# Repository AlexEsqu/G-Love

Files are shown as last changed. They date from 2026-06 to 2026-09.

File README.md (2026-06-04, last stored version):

https://app.notion.com/p/G-Love-Module-Electronique-06-26-42-Chips-371a25cc104180e3b6d8d438b70a2ca8

# Presentation

[G-Love] est un projet de conception d’un système de vêtement électronique (wearable) porté sur les bras., intégrant des bandes LEDSs RGB réactives à l’environnement et aux mouvements du porteur. (acceleration, flexion, pression)

Le système se présente sous forme de gant relié à une manchette d’avant-bras parcourus de capteurs et de LEDs. Un capteur sur le poignet permet de naviguer entre les modes.

---

# Table des matieres

---

# 1.Manuel d’utilisation

## Interactions

- Sur flexion / pression d’un doigt : animation localisée sur le segment correspondant
- Mouvement brusque du bras : traînée lumineuse, onde ?
- Orientation du bras : dégradé de couleur selon l’axe
- Bonus DMX : LEDs pilotees par reception DMX / Gestion d’une scene en transmission DMX

## Parametrage

- Pression bracelet : changement de mode pour passer d’un preset a l’autre
- Switch : pour demarrer avec ou sans feature LEDs
- Calibrage : via proximite aimant ou combinaison mouvement ?
- Bonus Touchscreen : Changer de mode / couleur

## Demarrage

Un utilisateur devra passer par une étape de calibration pour sa première utilisation du gant (longueur du bras et des doigts, amplitude de mouvement, calibration des senseurs…).
Mais les utilisations suivantes ne devraient pas nécessiter de vraie calibration, placer une nouvelle position d’origine au plus.

## Résumé

Les senseurs du gant devraient permettre de mesurer en temps réel la position de la main dans l’espace, la flexion des doigts, et les contacts avec le bout des doigts.

Les differents capteurs utilisés simultanément devraient permettre a l’utilisateur de déclencher plusieurs effets lumineux sur le display led, avec des combinaisons additives d’effets (mouvement + position des doigts X != mouvement + position Y != mouvement seul)

Ces mesures peuvent aussi être transmises en temps réel à une autre machine (à définir) pour lier ces mesures d’inputs à d’autres effets.

# 2.Features

---

## Mandatory

- 5 Ruban LED adressable sur les doigts, réagissant individuellement
- Interaction sur flexion d’un doigt (capteur flex a chaque doigt)
- Interaction sur pression du bout d’un doigt (capteur pression au bout de chaque doigt)
- Interaction sur :
    - mouvement de la main
    - l’orientation de la main
- Transmission coordonnée dans l’espace en temps réel par UART (précision dans la limite du matériel accessible avec le budget : plusieurs IMU, ou IMU plus précis, balise et triangulation…)
- Surface avant-bras LED adressable 16x16 / 16x64 (dans limite budget)
- Interaction sur l’avant bras (capteur pression)
- Envoi des donnees en USB via bridge USB to UART
- Système de reset des positions/mouvements (simple bouton ou combinaison d’input). Peut être nécessaire suivant le fonctionnement du capteur et la longueur d’utilisation.
- Système de calibration capable définir nouvelle origine (point 0,0,0) , sans reset tout le système. (si la calibration a été faite, un reset complet de la machine peut etre rattrappe en 2secondes si l’utilisateur garde une position de repos)

    Définir amplitude max du bras (bras tendu, leve, a plat sur les cuisses)

- Gestion embarquée de la chaleur des LEDs par capteur température et optimisation software ; utiliser des techno type textile conducteur, ??? pour permettre PLUS DE LED

## Bonus

#### Communication

- Interaction entre 2 gants dans le meme espace via coordonnees transmises en USB

#### TouchScreen

- Bonus: Touchscreen ou autre système d’input pour changer de mode/paramètres.

    Peut etre utile pour changer plus facilement les options pendant l‘utilisation de l’objet. Et pour visualiser les paramètres actuels sans trop perturber le display principal de l’objet.

#### DMX

- Bonus: Transmission DMX via driver RS-485 (MAX485 + XLR DMX)

    +Note: émission de format DMX probablement ingérable, réception semble plus réaliste.

#### FingerTip

- Bonus: Module Plug and Play HEARTBEAT capteur de pouls
- Bonus: Module Plug and play PISTODOIGT en infrarouge pour jouer au laser tag avec un doigt canon et le flex d’un autre doigt pour la gâchette  🔫
- Super Bonus : Module Plug and Play CURSOR permettant de dessiner en 3D ; Captation suffisamment précise pour dessiner un 42 lisible dans l’espace d’un 1m3

---

# 3. Schema fonctionnel

!Schema Fonctionnel.png

TO DO:
- formes logique
- légende
- ajouter ref compo

---

# 4. Matériel et protocoles

- **Microcontrôleurs relies UART** :
    - ATmega328P
    - ATmega32U4 (1 controleur principal pour les gouverner tous)
- **Bandes LEDs RGB** : WS2812B ou APA102 le long des doigts et panneau LEDs sur l’avant-bras
- **Capteurs** :

    **ADC** protocole **: Flex sensors** pour la flexion (duh), **FSR** (force-sensing resistor) pour la pression des doigts via multiplexeur CD4067

    **SPI / I2c** protocole **: IMU** (inertial measurement unit) pour accéléromètre + gyroscope,

    **Proximité** : Capteur Hall digital A3144

- **Support** : PCB Flex et PCB rigides avec segments flexibles entre chaque
- **Microcontrôleurs relies en UART** :
    - **ATmega328P (**main**)**
    - **ATmega2561** (avant-bras)
- **Capteurs** :

    **ADC** via multiplexer CD4067 **:**

    - **Flex sensors** pour la flexion des doigts
    - **FSR** (force-sensing resistor) pour la pression des doigts

    **I2C : IMU** (inertial measurement unit) pour accéléromètre + gyroscope

    **Digital I/O** :

    - **Capteur** Hall digital A3144
    - **bandes LEDs RGB** APA102 le long des doigts et panneau LEDs sur l’avant-bras
- **HeatSensor :** Utilisation de Thermistance NTC (negative temperature coefficient = la résistance diminue lorsque la température augmente), placé là où il y a le plus de variation de chaleur possible (rubans LED) avec de la colle thermique pour mieux capté la chaleur et recouvert d’un ruban Kapton pour isolé de l’air ambiant

- **Bonus SPI/I2C** : touchscreen, **GC9A01** est la puce qui contrôle l'affichage de l'écran et communique en SPI et **CST816D** est la puce qui contrôle la détection du tactile, communique en I2C
    - En sortie (Affichage - GC9A01) :
        - Afficher le mode d'interaction actuel (ex: "Mode DMX", "Mode Laser Tag")
        - Afficher des retours visuels lors de l'étape de calibration
    - En entrée (Saisie tactile - CST816D) :
        - Changement de mode: changement de mode pour différent interaction prédefini
        - Parametrage de couleurs: afficher une roue chromatique sur l'écran, permettant à l'utilisateur de sélectionner directement au doigt la couleur de base de ses bandes LED.
        - Bouton de secours / de reset: permet de déclencher manuellement un recalibration ou un “reset” en appuyant sur un bouton
- **Bonus UART** : USB
- **Bonus UART** : DMX
- **Support** : PCB Flex et PCB rigides avec segments flexibles entre chaque

## SPI (**Serial Peripheral Interface**)

SPI est un protocole ultra-rapide avec 4 fils : MOSI, MISO, SCK, CS. Fonctionnant sur une architecture de type master/slave, il permet des transferts de données bidirectionnels simultanenent  sans ralentir le microcontrôleur principal.

La synchronisation des échanges est assuré par un signal d’horloge généré exclusivement par le microcontroleur configuré en maitre

Le bus SPI repose sur l’utilisation de quatre lignes de signaux:

- SCK(Serial Clock) : Signal d’horloge generé par le maitre, il cadence le rythme de transmission des bits de données
- MOSI(Master Out Slave In) : Ligne de données unidirectionelle transportant les informations du maitre vers le slave
- MISO(Master In Slave Out) : ligne de données unidirectionelle transportant les informations du slave vers le maitre
- CS / SS (Chip Select / Slave Select) : Ligne d’activation dédié a chaque composant esclave, ce signal est actif a l’etat bas (0V), tant que le signal d’un esclave est haut, celui ci ignore le bus SPI et libere la ligne MISO
- Composant : Ruban LED APA102 (avant-bras).
    - **Le Maître :** L'ATmega328P est le maître du bus SPI
    - **Esclave :** Bandes LEDs APA102
    - **L'Usage :** Mise à jour à très haute fréquence de la matrice visuelle de l'avant-bras
    - **Câblage** : Utilise le D11(MOSI - Données) et D13 (SCK - Horloge)
- Composant : Ecran GC9A01
    - **Le Maitre** : L’ATMega2561 est le maitre du bus SPI
    - **Esclave :** L’écran GC9A01,
    - **L'Usage :** Le protocole SPI est un protocole assez rapide pour travailler et rafraichir un écran de 240x240pixels
    - **Cablage** : PB1(SCK - Horloge), PB2 (MOSI - Données), PB0 (SS/CS - Selection de l’ecran)

Les LED WS2812B utilise un protocole propriétaire de communication monofil, l’envoi des données à ces LED peut bloquer l’execution du programme et desactive les interruption du microcontrolleur

En choisissant les LED APA102 fonctionnant en SPI, la transmission de données est cadencée par la ligne d’horloge matérielle (SCK).  L’ATMega328P peut rafraichir l’affichage des LED sans aucune contrainte de temps grace au protocole SPI, lui permettant de simultanément et sans latences les capteurs

L’utilisation du protocole SPI pour l’affichage de l’ecran du TouchScreen permet aussi d’atteindre un taux de rafaichissement d’écran plus élevé et fluide avec 8MHz avec l’atm2561 contre 400kHz en I2C

## I2C **(Inter-Integrated Circuit)**

Le protocole I2C est un standard de communication bidirectionnel, il repose sur un principe d’adressage logiciel et permet de facilement reliée un microcontrolleur et différents circuits.

Contrairement au SPI qui necessite une ligne individuelle (Chip Select) par peripherique, le protocole I2C permet de connecter plusieurs dizaines de composants en parallele sur seulement deux lignes de communication:

- SCL (Serial Clock) : Signal d’horloge generé par le maitre pour cadencer la transmission des bits
- SDA (Serial Data) : Ligne de données bidirectionnelle transportant alternativement les informations du maitre vers le slave, et du slave vers le maitre

Adressage Unique: Chaque esclave I2C possède une adresse codée en binaire définie en usine ou par configuration matérielle. Le maitre commence chaque interaction en envoyant l’adresse du composant visé sur le fil SDA. Seul le composant possédant cette adresse répond, les autres ignorant la suite des paquets.

- Composant : ICM-42699-P
    - **Le Maitre** : L’ATMega328P est le maitre du bus I2C
    - **Esclave :**  ICM-42699-P
    - **L'Usage :** Le protocole I2C est
    - **Cablage** : SDA et SDL
- Composant : ecran tactile CST816D
    - **Le Maitre** : L’ATMega2561 est le maitre du bus I2C
    - **Esclave :**  CST816D
    - **L'Usage :** Le protocole I2C est
    - **Cablage** : SDA et SDL

L’adoption de l’I2C pour la gestion des capteurs de position et l’interaction tactile du TouchScreen:

- Minimisation de l’encombrement du cablage
    - L’I2C permet de connecter l’IMU et l’ecran tactile en n’utilsaint que 2 lignes de données, evitant de saturer les pins des micronctrolleur et d’alourdir le cablage flexible du bras
- Echange de données plus lent
    - Contraireemnt à l’écran LCD, le tactile et l’IMU ne transmettenet que de petit paquets de données, la vitesse de l’I2C est suffisante pour l’echange de donnée

## UART (Universal Asynchronous Receiver-Transmitter)

## ADC

## DIGITAL I/O

---

# 5. Pinout

## ATmega328p — Concentrateur capteurs + APA102

### MANDATORY

#### ALIMENTATION & PROGRAMMATION

| Pin | Composant | Signal / rôle | Protocole |
| --- | --- | --- | --- |
| **VCC / GND** | Alim | 5V — 100nF par paire VCC/GND | PWR |
| **RESET** | Reset | Pull-up 10kΩ vers VCC | Reset |

---

#### CRYSTAL OSCILLATOR

| Pin | Composant | Signal / rôle | Protocole |
| --- | --- | --- | --- |
| **B6 / XTAL1** | Crystal / Oscillator | External Clock |  |
| **B7 / XTAL2** | Crystal / Oscillator | External Clock |  |

---

#### ADC + MULTIPLEXER

| Pin | Composant | Signal / rôle | Protocole |
| --- | --- | --- | --- |
| **C0** | CD4067 S0 | Sélection canal multiplexeur | Digital |
| **C1** | CD4067 S1 | Sélection canal multiplexeur | Digital |
| **C2** | CD4067 S2 | Sélection canal multiplexeur | Digital |
| **C3** | CD4067 S3 | Sélection canal multiplexeur | Digital |
| **ADC7** | CD4067 output | Multiplex FSR doigts + Flex | ADC |
| **ADC6** | FSR 402 poignet | Capteur de force | ADC |

---

#### I2C IMU

| Pin | Composant | Signal / rôle | Protocole |
| --- | --- | --- | --- |
| **C4 / SDA** | ICM-42688 | IMU SDA | I2C |
| **C5 / SCL** | ICM-42688 | IMU SCL | I2C |

---

#### GPIO Hall

| Pin | Composant | Signal / rôle | Protocole |
| --- | --- | --- | --- |
| **D6** | A3144 Hall | Capteur magnétique | GPIO |

---

#### SPI LEDs

| Pin | Composant | Signal / rôle | Protocole |
| --- | --- | --- | --- |
| **B4** | APA102 ruban #1 | CS ruban 1 | GPIO CS |
| **B3 / MOSI** | APA102 DI (tous) | Data SPI — bus commun | SPI HW |
| **B5 / SCK** | APA102 CI (tous) | Clock SPI — bus commun | SPI HW |

---

#### BONUS UART

| Pin | Composant | Signal / rôle | Protocole |
| --- | --- | --- | --- |
| **D0 / RX** | ATmega2561 | RX ← TX du 2561 | UART |
| **D1 / TX** | ATmega2561 | TX → RX du 2561 | UART |

---

#### RECAP

| Pin | Composant | Signal / rôle | Protocole |
| --- | --- | --- | --- |
| **C0** | CD4067 S0 | Sélection canal multiplexeur | Digital |
| **C1** | CD4067 S1 | Sélection canal multiplexeur | Digital |
| **C2** | CD4067 S2 | Sélection canal multiplexeur | Digital |
| **C3** | CD4067 S3 | Sélection canal multiplexeur | Digital |
| **ADC7** | CD4067 output | Multiplex FSR doigts + Flex | ADC |
| **D6** | A3144 Hall | Capteur magnétique | Digital IN |
| **B4** | APA102 ruban #1 | CS ruban 1 | GPIO CS |
| **B3 / MOSI** | APA102 DI (tous) | Data SPI — bus commun | SPI HW |
| **B5 / SCK** | APA102 CI (tous) | Clock SPI — bus commun | SPI HW |
| **ADC6** | FSR 402 poignet | Capteur de force | ADC |
| **C4 / SDA** | ICM-42688 | IMU SDA | I2C |
| **C5 / SCL** | ICM-42688 | IMU SCL | I2C |
| **B6 / XTAL1** | Crystal / Oscillator | External Clock |  |
| **B7 / XTAL2** | Crystal / Oscillator | External Clock |  |
| **VCC / GND** | Alim | 5V — 100nF par paire VCC/GND | PWR |
| **RESET** | Reset | Pull-up 10kΩ vers VCC | Reset |

| **D0 / RX** | ATmega2561 | RX ← TX du 2561 | UART |
| --- | --- | --- | --- |
| **D1 / TX** | ATmega2561 | TX → RX du 2561 | UART |

---

## BONUS A FINIR

## ATmega2561 — Display + bus + périphériques

#### ALIMENTATION & PROGRAMMATION

| Pin | Composant | Signal / rôle | Protocole |
| --- | --- | --- | --- |
| **VCC / GND** | Alim | 5V — 100nF par paire VCC/GND | PWR |
| **RESET** | Reset | Pull-up 10kΩ vers VCC | Reset |

---

#### CRYSTAL OSCILLATOR

| Pin | Composant | Signal / rôle | Protocole |
| --- | --- | --- | --- |
| **XTAL1** | Crystal / Oscillator | External Clock |  |
| **XTAL2** | Crystal / Oscillator | External Clock |  |

#### UART0 — Lien vers ATmega328p

| Pin | Composant | Signal / rôle | Protocole |
| --- | --- | --- | --- |
| **E0** | ATmega328p | RX ← TX du 328p | UART0 |
| **E1** | ATmega328p | TX → RX du 328p | UART0 |

#### UART1 — USB via FTDI FT232R / Bus RS-485 via MAX487

| Pin | Composant | Signal / rôle | Protocole |
| --- | --- | --- | --- |
| **D2 / TXD2** | 74HC4053 | TX → FTDI RX / MAX487 DI | UART1 |
| **D3 / RXD2** | 74HC4053 | RX ← FTDI TX (1kΩ série) / MAX487 RO | UART1 |
| **D5** | 74HC4053 | Switch Digital | GPIO |
| **D4** | GPIO | MAX487 DE + ~RE (liés ensemble) | GPIO |

#### **Module TouchScreen (GC9A01 + CST816D) avec LevelShifter TXS0108EPWR**

| Pin | Composant | Signal / rôle | Protocole |
| --- | --- | --- | --- |
| PB0 | ~SS / CS | LCD CS | GPIO CS |
| PB1 | SCK | SCLK | SPI |
| PB2 | MOSI | MOSI | SPI |
| PB3 | MISO | MISO | SPI |
| PB4 | GPIO | LCD DC / RS | GPIO |
| PB5 | GPIO | LCD RST | GPIO |
| PD0 | SCL I2C | Touchscreen SCL | I2C |
| PD1 | SDA I2C | Touchscreen Data | I2C |
| PE4 | INT4 | Touchscreen Interrupt | I2C |

#### Plug & play (pouls / IR) + switch pression

| Pin | Composant | Signal / rôle | Protocole |
| --- | --- | --- | --- |
| **PE2** | INT2 | Capteur pouls / IR — signal data | INT ext. |
| **PE3** | GPIO | Détection présence connecteur (pull-up) | GPIO |
| **PE4** | INT4 | Switch pression — interrupt | INT ext. |

# 6. BOM

| Component | QTY | Prix unitaire (€) | Prix total (€) | Fournisseur |
| --- | --- | --- | --- | --- |
| **ATMega328P** | 1 | 2,26 | 2,26 | https://www.digikey.fr/fr/products/detail/microchip-technology/ATMEGA328P-AU/1832260 |
| **ATMega2561** | 1 | 13,17 | 13,17 | https://www.digikey.fr/fr/products/detail/microchip-technology/ATMEGA2561-16AU/735457 |
| **Interlink FSR 400 short (FSR doigt)** | 5 | 4,886 | 24,43 | https://www.digikey.fr/fr/product-highlight/i/interlink/fsr-400-round-force-sensing-resistor |
| **Spectra Symbol SEN-10264 2.2” (Flex Sensor)** | 4 | 10,16 | 40,64 | https://www.digikey.fr/fr/products/detail/sparkfun-electronics/10264/17829611 |
| **Interlink FSR 402 medium (FSR avant bras)** | 1 | 6,05 | 6,05 | https://www.digikey.fr/en/product-highlight/i/interlink/fsr-402-round-force-sensing-resistor |
| **Multiplexer CD4067**  | 1 | 0,79 | 0,79 | https://www.digikey.fr/fr/products/detail/texas-instruments/CD4067BM96/1691267 |
| **Capteur Effet Hall A3144** | 1 | 0,20 | 0,99 (pour 5) | https://fr.aliexpress.com/item/1005007195591707.html |
| **Aimant neodyme** | 1 | 0,99 | 0,99 (pour 20?) | https://fr.aliexpress.com/item/1005010078861287.html |
| **ICM-42688-P (IMU)** | 1 | 4,17 | 4,17 | https://www.digikey.fr/fr/products/detail/tdk-invensense/ICM-42688-P/10824934 |
|  |  |  |  |  |
| **Ruban LED APA102 (1m, 144 LED)** | 1 | 14,39 | 14,39 | https://fr.aliexpress.com/item/32969463242.html |
| **Panneau LED 16x16 (256 LEDs)** | 1 | Deprecated |  |  |
| **Panneau LED 16x32 (512 LEDs)** | 1 | Deprecated |  |  |
| **Panneau LED 16x64 (1024 LEDs)** | 1 | Deprecated |  |  |
| **Ruban LED Homemade (LEDs unitaires)** | ? |  |  |  |
|  |  |  |  |  |
| **MAX485 (DMX)** | 1 | 6,74 | 6,74 | https://www.digikey.fr/en/products/detail/analog-devices-inc-maxim-integrated/MAX485ESA/1495323 |
| **Module GC9A01 + CST816D (TouchScreen)** | 1 | 3,89 | 3,89 | https://fr.aliexpress.com/item/1005011785235078.html |
| **Module GC9A01 + CST816D (TouchScreen)** | 1 | 6,59 | 6,59 | https://fr.aliexpress.com/item/1005012175753162.html |
| **PCB** | 2 | TBH | TBH |  |
| **TXS0108E (**Level Shifter ATM - Touchscreen) | 1 | 1,46 |  | https://www.digikey.fr/fr/products/detail/texas-instruments/TXS0108EPWR/1775302 |
| **TXS0104E** (Level Shifter ATM - IMU) | 1 | 0,92 |  | https://www.digikey.fr/fr/products/detail/texas-instruments/TXS0104EPWR/1143662 |
| **Crystal 16MHz** | 2 | 0,89 | 1,78 | https://www.digikey.fr/fr/products/detail/epson/FA-238-16-0000MB-C3/2403378 |
|  |  |  |  |  |
| Condensateur céramique de découplage 100nF | 4 |  |  |  |
| Condensateur electrolityque de découplage 10mF | 1 |  |  |  |
| Self/Inductance/Bobine/FiltreLC 10 uH | 1 |  |  |  |
| Resistance 10kΩ (pour chaque FSR) | 5 |  |  |  |
|  |  |  |  |  |
| Thermistance 10kΩ | ? |  |  |  |
| Colle Thermique | 1 |  |  |  |
| Ruban Kapton | 1 |  |  |  |
|  |  |  |  |  |
| ***TOTAL*** |  |  |  |  |

# 7.Charge d’alimentation

| Component | QTY | Tension (U) | Max intensity unitaire (I) | Max intensity (I) | Power (P) |
| --- | --- | --- | --- | --- | --- |
| **ATMega328P** | 1 | 5V | 14mA | 14mA | 0,07W |
| **ATMega2561** | 1 | 5V | 14mA | 14mA | 0,07W |
| **Interlink FSR 400 short (FSR)** | 5 | 5V | ~1mA | 5mA | 0,025 W |
| **Spectra Symbol SEN-10264 2.2” (Flex Sensor)** | 4 | 5V | ~1mA | 4mA | 0,020 W |
| **Interlink FSR 402 medium (FSR)** | 1 | 5V | ~1mA | 1mA | 0,005W |
| **ICM-42688-P (IMU)** | 1 | 3.3V | ~1mA | 1mA | 0,003 W |
| **Capteur Effet Hall A3144** | 1 | 5V | ~9mA | 9mA | 0,045 W |
|  |  |  |  |  |  |
| **Ruban LED APA (1m, 144 LED)** | 1 | 5V | 144*60mA = 8,64A | 144*60mA = 8,64A | 43,2 W |
| **Panneau LED 16x16 (256 LEDs)** | 1 | 5V | 256*60mA = 15,36A | 256*60mA = 15,36A | 76,80 W |
| **Panneau LED 16x32 (512 LEDs)** | 1 | 5V | 512*60mA = 30,72A | 512*60mA = 30,72A | 153,6 W |
| **Panneau LED 16x64 (1024 LEDs** | 1 | 5V | 1024*60mA = 61,44A | 1024*60mA = 61,44A | 307,2 W |
| **Ruban LED Homemade (LEDs unitaires)** | 100 | 5V | 60mA | 100*60mA = 6A | 30 W |
|  |  |  |  |  |  |
| **MAX485 (DMX)** | 1 | 5V | 0,9mA | 0,9mA | 0,0045 W |
| **Module GC9A01 + CST816D (TouchScreen)** | 1 | 3,3V | 100mA | 100mA | 0,33 W |
|  |  |  |  |  |  |
|  |  |  |  |  |  |

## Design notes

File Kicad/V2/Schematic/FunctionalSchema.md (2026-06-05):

```mermaid
%%{init:
	{'flowchart':
		{
			'curve': 'basis',
			'nodeSpacing':50,
			'rankSpacing': 20,
			'htmlLabels': true,
			'useMaxWidth': true,
		},
		'theme': 'base'
	}
}%%

graph

	subgraph Hand["Hand - ATmega 328P"]

		%% Input
		HandIMU@{ shape: stadium, label: "<b>IMU</b><br>ICM-42688-P<br><i>Hand</i>" }
		HandHallCaptor@{ shape: stadium, label: "<b>Hall Sensor</b><br>A3144<br><i>Hand</i>" }
		ForearmForceResistanceSensor@{ shape: stadium, label: "<b>Force Sensor</b><br>Interlink FSR 402<br><i>Forearm</i>" }
		MultiplexerFlex@{ shape: inv-trapezoid, label: "Multiplexer Flex<br>CD4067" }
		FingerFlexSensors@{ shape: stadium, label: "4x <b>Flex Sensors</b><br>SEN-10264<br><i>Fingers</i>" }
		FingerForceResistanceSensor@{ shape: stadium, label: "4x <b>Force Sensor</b><br>Interlink FSR 400<br><i>Fingertips</i>" }

		%% Output
		LedDoigts5@{ shape: lean-right, label: "4x 20cm <b>LED Band</b><br>APA102 144 LED/m<br><i>Fingers</i>" }
		LedBras@{ shape: lean-right, label: "LED Surface<br><i>Forearms</i>" }

		%% Central
		MicrochipHand@{ shape: rect, label: "ATmega 328P" }

	end

	subgraph Arm["Arm - ATmega 2561"]

		%% Input
		HeartSensorRTD@{ shape: stadium, label: "Heart Sensor RTD<br><i>Forearms</i>" }

		%% FINGERTIPS (modular addons)
		subgraph FingerTips

			PogoReception@{ shape: trapezoid, label: "Pogo"}

			subgraph FingertipHeartbeat["Heartbeat"]
				ATtinyHeartBeat@{ label: "AT tiny HeartBeat"}
				PulseSensor@{ shape: stadium, label: "Pulse Sensor<br><i>Fingertips</i>" }
				PogoHeartbeat@{ shape: trapezoid, label: "Pogo Heartbeat"}
			end

			subgraph FingertipCursor["Cursor"]
				ATtinyCursor@{ label: "AT tiny Cursor"}
				FingerIMU@{ shape: stadium, label: "IMU<br><i>Fingertips</i>" }
				PogoCursor@{ shape: trapezoid, label: "Pogo Cursor"}
			end

			subgraph FingertipGun["Pistodoigt"]
				ATtinyPistodoigt@{ label: "AT tiny Pistodoigt"}
				LaserPointer@{ shape: lean-right, label: "Laser Pointer<br><i>Fingertips</i>" }
				PogoPistodoigt@{ shape: trapezoid, label: "Pogo Pistodoigt"}
			end

		end

		%% Output
		Touchscreen@{ shape: lean-right, label: "<b> TouchScreen </b> <br>GC9A01 & CST816D <br><i>Wrist</i>" }
		MultiplexerUart@{ shape: inv-trapezoid, label: 4x "\" Multiplexer\" UART<br>Digital Switch 74LVC1G3157" }
			DriverDMX@{ shape: trapezoid, label: "DMX Driver" }
			DriverUSB@{ shape: trapezoid, label: "USB Driver" }
			DriverSecondGlove@{ shape: trapezoid, label: "USB Driver" }

		%% Central processor
		MicrochipArm@{ shape: rect, label: "ATmega 2561" }

	end

	subgraph Glossary["Shape Glossary"]
		G_Sensor@{ shape: stadium, label: "Sensor" }
		G_Chip@{ shape: rect, label: "Microchip" }
		G_Mux@{ shape: inv-trapezoid, label: "Multiplexer" }
		G_Out@{ shape: lean-right, label: "Output" }
		G_Conn@{ shape: trapezoid, label: "Connector" }
		G_Sensor ~~~ G_Chip ~~~ G_Mux ~~~ G_Out ~~~ G_Conn
	end

	HandIMU -.-> |I2C| MicrochipHand
	HandHallCaptor -->|GPIO| MicrochipHand
	ForearmForceResistanceSensor -->|ADC| MicrochipHand

	MultiplexerFlex -->|GPIO| MicrochipHand
	FingerFlexSensors -->|ADC| MultiplexerFlex
	FingerForceResistanceSensor -->|ADC| MultiplexerFlex

	MicrochipHand -->|SPI| LedDoigts5
	MicrochipHand -->|SPI| LedBras

	HeartSensorRTD -->|ADC| MicrochipArm

	MicrochipHand <==>|UART| MicrochipArm
	%% MicrochipHand ~~~ MicrochipArm

	MicrochipArm <==>|UART| MultiplexerUart
	MultiplexerUart <==>|UART| DriverDMX
	MultiplexerUart <==>|UART| DriverUSB
	MultiplexerUart <==>|UART| DriverSecondGlove

	MicrochipArm <-.->|I2C| PogoReception

	PogoReception <-.->|I2C| PogoHeartbeat
	PogoHeartbeat <-.->|I2C| ATtinyHeartBeat
	ATtinyHeartBeat <-.->|ADC| PulseSensor

	PogoReception <-.->|I2C| PogoCursor
	PogoCursor <-.->|I2C| ATtinyCursor
	ATtinyCursor <-.->|I2C| FingerIMU

	PogoReception <-.->|I2C| PogoPistodoigt
	PogoPistodoigt <-.->|I2C| ATtinyPistodoigt
	ATtinyPistodoigt <-.->|GPIO| LaserPointer

	MicrochipArm -->|SPI| Touchscreen
	Touchscreen -.->|I2C| MicrochipArm

	%% Style

	classDef sensor padding:0px,font-size:11px,fill:#FFF9C4,stroke:#D97706,stroke-width:2px,color:#000
	classDef chip padding:0px,font-size:11px,fill:#DBEAFE,stroke:#1D4ED8,stroke-width:2px,color:#000
	classDef multiplexer padding:0px,font-size:11px,fill:#EDE9FE,stroke:#7C3AED,stroke-width:2px,color:#000
	classDef led padding:0px,font-size:11px,fill:#DCFCE7,stroke:#16A34A,stroke-width:2px,color:#000
	classDef connector padding:0px,font-size:11px,fill:#FED7AA,stroke:#C2410C,stroke-width:2px,color:#000

	class HandIMU,HandHallCaptor,FingerFlexSensors,FingerForceResistanceSensor,ForearmForceResistanceSensor,PulseSensor,FingerIMU,HeartSensorRTD sensor
	class MicrochipHand,MicrochipArm,ATtinyHeartBeat,ATtinyCursor,ATtinyPistodoigt chip
	class MultiplexerFlex,MultiplexerUart multiplexer
	class LedDoigts5,LedBras,LaserPointer,Touchscreen led
	class PogoReception,PogoHeartbeat,PogoCursor,PogoPistodoigt,DriverDMX,DriverUSB,DriverSecondGlove connector

	class G_Sensor sensor
	class G_Chip chip
	class G_Mux multiplexer
	class G_Out led
	class G_Driv driver
	class G_Conn connector

```

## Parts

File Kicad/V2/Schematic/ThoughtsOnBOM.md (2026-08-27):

# DEFINITIONS

## Condensateur

### Condensateur Céramique
Utilise un matériaux céramique comme diélectrique
Généralement de 1 pF à 100 μF
Non polarisé (donc utilisable en AC)
Faible cout
Stable (plusieurs décennies)
Faibles pertes
Petit & léger
Généralement un petit disque plat

### Condensateur Électrolytique (en aluminium)
Utilise un électrolytique comme diélectrique
Généralement de 1 µF à 100 mF
Polarisé
Capacité élevée
Haute tension nominale
Résistance série équivalente (ESR) élevée (beaucoup de dissipation par chaleur)
Durée de vie limitée (1000s d'heures)
Généralement un cylindre épais

## Non Actuated
Not powered ??

## Hysteresis

## Capacitor on ATMega328P
https://www.raypcb.com/capacitor-for-arduino/

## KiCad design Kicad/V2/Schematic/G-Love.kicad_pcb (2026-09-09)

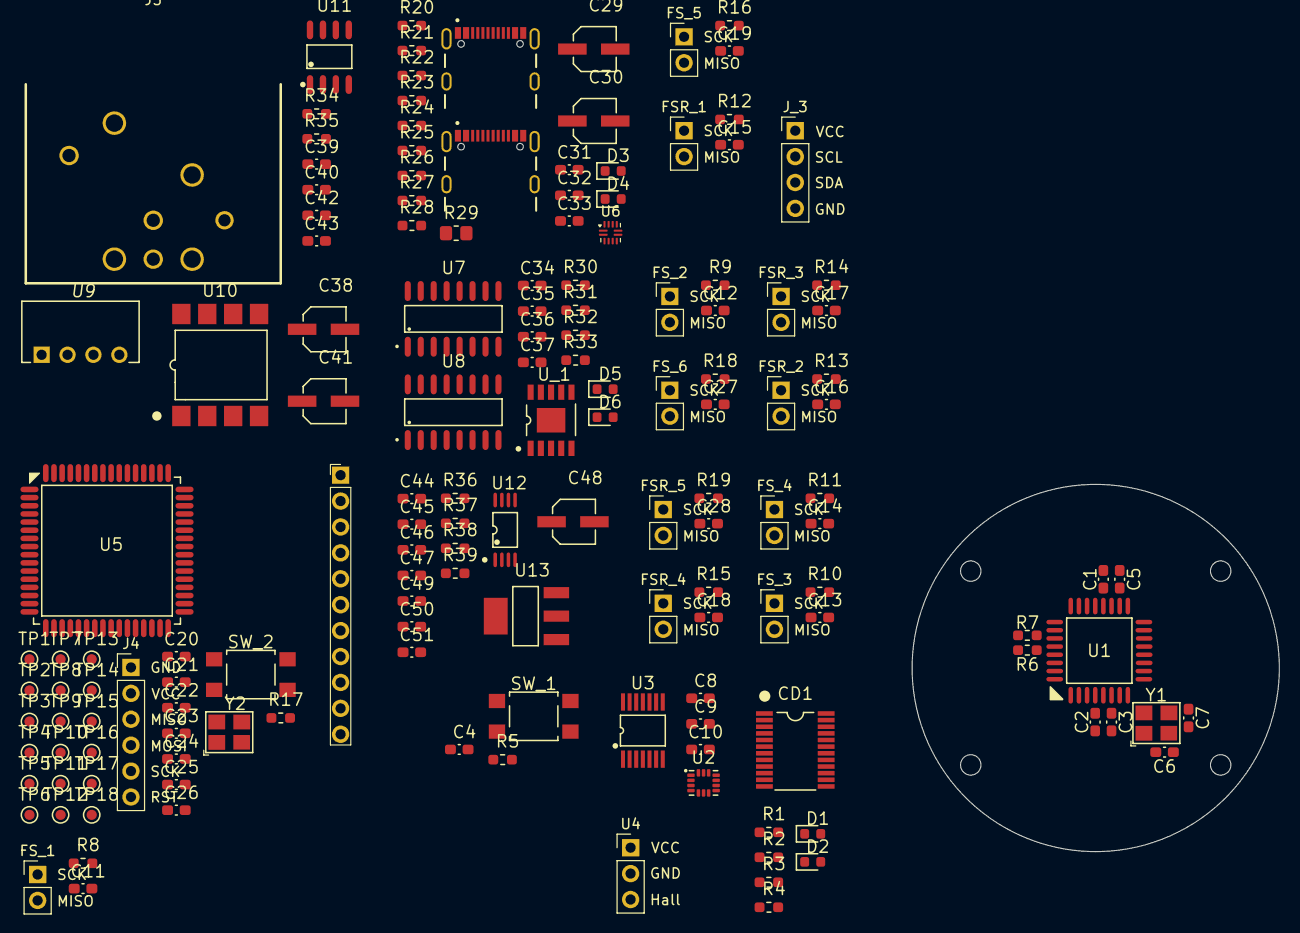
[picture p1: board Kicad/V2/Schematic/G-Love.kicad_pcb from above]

Board: 2 copper layers, 36.0 x 36.0 mm, 150 parts (0 on the bottom side), 101 nets, no tracks yet.

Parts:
C1, C2, C3, C4, C5, C22, C23, C24, C25, C26, C33, C34, C35, C36, C37, C39, C40, C42, C43, C47, C49, C51: 100nF; Capacitor_0603
C6, C7, C20, C21: 12pF; Capacitor_0603
C8, C31: 10nF; Capacitor_0603
C9: 2.2nF; Capacitor_0603
C10: 0.1nF; Capacitor_0603
C11, C12, C13, C14, C15, C16, C17, C18, C19, C27, C28: 47pF; Capacitor_0603
C29, C30, C38, C41, C48: 4.7uF; Capacitor_Electrolytic
C32: 10n; Capacitor_0603
C44, C45, C46: 1uF; Capacitor_0603
C50: 10uF; Capacitor_0603
CD1: CD4097B
D1, D2, D5, D6: YELLOW; LED
D3, D4: RED; LED
FSR_1, FSR_2, FSR_3, FSR_4, FSR_5: PinHeader_1x02_P2.54mm_Vertical
FS_1, FS_2, FS_3, FS_4, FS_5, FS_6: PinHeader_1x02_P2.54mm_Vertical
J3: PinHeader_1x11_P2.54mm_Vertical
J4: PinHeader_1x06_P2.54mm_Vertical
J5: XLR5_Ground; XLR5_Connector_Female_CONN-TH_NC5FAH
J_1, J_2: Conn_USB_Receptacle; USB_C_Receptacle_GCT_USB4105-xx-A_16P_TopMnt_Horizontal
J_3: PinHeader_1x04_P2.54mm_Vertical
R1, R2, R6, R7: 2.2kΩ; Resistor_0603
R3, R4: 1K; Resistor_0603
R5, R8, R9, R10, R11, R12, R13, R14, R15, R16, R17, R18, R19, R28, R37, R39: 10kΩ; Resistor_0603
R20, R21, R30, R31, R32, R33: 1k; Resistor_0603
R22, R23: 1M; Resistor_0603
R24, R25, R26, R27: 5.1k; Resistor_0603
R29: 900K; Resistor_0805
R34: 330R; Resistor_0603
R35: 4.7k; Resistor_0603
R36: 560R; Resistor_0603
R38: 47k; Resistor_0603
SW_1, SW_2: SW_SPST_TL3305A
TP1, TP2, TP3, TP4, TP5, TP6, TP7, TP8, TP9, TP10, TP11, TP12, TP13, TP14, TP15, TP16, TP17, TP18: TestPoint_Pad_D1.0mm
U1: ATMega328P; ATMega328P-AU
U2: ICM-42688-P_I2C; ICM-42688-P
U3: TXS0104E; TXS0104EPWR
U4: Hall Sensor A3144; PinHeader_1x03_P2.54mm_Vertical
U5: ATMEGA2561-16AU; ATMega2561
U6: TUSB321; Texas_X2QFN-12_1.6x1.6mm_P0.4mm
U7, U8: 74HC4052
U9: B0505S-1W1; B0505S
U10: 6N137
U11: MAX485E; MAX485ED
U12: TPS2113APWR; TPS2113
U13: AMS1117
U_1: CH340K
Y1, Y2: 16MHz; Crystal_16MHz

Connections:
5VL: C44.1, C47.1, R37.2
+3.3V: C8.2, C9.1, C10.1, C50.1, C51.1, U2.5 (VDDIO), U2.8 (VDD), U2.12 (VDDIO), U3.1 (V_{CCA}), U4.1 (VCC), U13.2 (Vout)
/ATMega2561/2561_MOSI: J3.10, U5.12 ((MOSI/PCINT2)_PB2)
/ATMega2561/2561_MUX_SELECT_A: U5.4 (PE2_(XCK0/AIN0)), U8.10 (A)
/ATMega2561/2561_MUX_SELECT_B: U5.5 (PE3_(OC3A/AIN1)), U8.9 (B)
/ATMega2561/2561_RXD1: D2.2 (K), U1.31 (TXD/PCINT17/PD1), U5.27 ((RXD1/INT2)_PD2)
/ATMega2561/2561_SCL: J3.5, J_3.2, R1.1, TP17.1, U5.25 ((SCL/INT0)_PD0)
/ATMega2561/2561_SCREEN_DC: J3.7, U5.14 ((OC2A/_PCINT4)_PB4)
/ATMega2561/2561_SCREEN_RESET: J3.8, U5.15 ((OC1A/PCINT5)_PB5)
/ATMega2561/2561_SDA: J3.4, J_3.3, R2.1, TP18.1, U5.26 ((SDA/INT1)_PD1)
/ATMega2561/2561_SS: J3.6, U5.10 ((~SS/PCINT0)_PB0)
/ATMega2561/2561_TOUCH_INT: J3.2, U5.16 ((OC1B/PCINT6)_PB6)
/ATMega2561/2561_TOUCH_RESET: J3.3, U5.17 ((OC0A/OC1C/PCINT7)_PB7)
/ATMega2561/2561_TXD1: D1.2 (K), U1.30 (RDX/PCINT16/PD0), U5.28 ((TXD1/INT3)_PD3)
/ATMega2561/2561_USB1_INT: U5.6 (PE4_(OC3B/INT4)), U6.7 (OUT1)
/ATMega2561/2561_USB2_INT: U5.8 (PE6_(T3/INT6)), U6.8 (OUT2)
/ATMega2561/DTR: C23.2, U5.7 (PE5_(OC3C/INT5)), U8.1 (Y0), U_1.4 (~DTR), U_1.8 (TXD)
/ATMega2561/MCU_2561_RESET: C23.1, J4.4, R17.1, SW_2.2, U5.20 (~RESET)
/ATMega2561/MISO_BOOT_2561: J4.2, R31.2, TP1.1, U5.3 (PE1_(TXD0/PDO))
/ATMega2561/MOSI_BOOT_2561: D6.2 (K), J4.3, R32.2, TP2.1, U5.2 (PE0_(RXD0/PCINT8/PDI))
/ATMega2561/SCK_BOOT_2561: J3.9, J4.5, U5.11 ((SCK/PCINT1)_PB1)
/ATmega328p/328P_ADC_MUX_INH: CD1.13 (INHIBIT), U1.26 (ADC3/PCINT11/PC3)
/ATmega328p/328P_ADC_MUX_SELECT_A: CD1.10 (A), U1.25 (ADC2/PCINT10/PC2)
/ATmega328p/328P_ADC_MUX_SELECT_B: CD1.11 (B), U1.23 (ADC0/PCINT8/PC0)
/ATmega328p/328P_ADC_MUX_SELECT_C: CD1.14 (C), U1.24 (ADC1/PCINT9/PC1)
/ATmega328p/328P_ADC_X_OUT: CD1.1 (X_OutIn), U1.22 (ADC7)
/ATmega328p/328P_ADC_Y_OUT: CD1.17 (Y_OutIn), U1.19 (ADC6)
/ATmega328p/328P_I2C_IMU_SCL: R6.1, U1.28 (SCL/ADC5/PCINT13/PC5), U3.12 (B2)
/ATmega328p/328P_I2C_IMU_SDA: R7.1, U1.27 (SDA/ADC4/PSCINT12/PC4), U3.13 (B1)
/ATmega328p/MCU_328P_RESET: R5.1, SW_1.2, U1.29 (~RESET/PCINT14/PC6)
/Data/power I/O/Data/DMX/TX_DMX: R34.1, U8.15 (X2)
/Data/power I/O/Data/SBU1: J_1.A8 (SBU1), U7.5 (Y1), U7.12 (X0)
/Data/power I/O/Data/SBU2: J_1.B8 (SBU2), U7.1 (Y0), U7.14 (X1)
/Data/power I/O/Data/UD+: J_1.A7 (D+), J_1.B6 (D+), U_1.1 (UD+)
/Data/power I/O/Data/UD-: J_1.A6 (D-), J_1.B7 (D-), U_1.2 (UD-)
/Data/power I/O/Data/USB_SELECT: R28.2, U6.11 (DIR), U7.10 (A)
/Hand_Captors/FSR_Index/TouchADC: C15.2, CD1.8 (X_1), FSR_1.1, R12.2
/Hand_Captors/FSR_Little/TouchADC: C16.2, CD1.5 (X_4), FSR_2.1, R13.2
/Hand_Captors/FSR_Middle/TouchADC: C28.2, CD1.7 (X_2), FSR_5.1, R19.2
/Hand_Captors/FSR_Ring/TouchADC: C17.2, CD1.6 (X_3), FSR_3.1, R14.2
/Hand_Captors/FSR_Thumb/TouchADC: C18.2, CD1.9 (X_0), FSR_4.1, R15.2
/Hand_Captors/Flex_Sensor0/FlexADC: C14.2, CD1.23 (Y_0), FS_4.1, R11.1
/Hand_Captors/Flex_Sensor1/FlexADC: C27.2, CD1.22 (Y_1), FS_6.1, R18.1
/Hand_Captors/Flex_Sensor2/FlexADC: C13.2, CD1.21 (Y_2), FS_3.1, R10.1
/Hand_Captors/Flex_Sensor3/FlexADC: C12.2, CD1.20 (Y_3), FS_2.1, R9.1
/Hand_Captors/Flex_Sensor4/FlexADC: C11.2, CD1.19 (Y_4), FS_1.1, R8.1
/Hand_Captors/Flex_Sensor5/FlexADC: C19.2, CD1.18 (Y_5), FS_5.1, R16.1
/Hand_Captors/HallCaptor/HallGPIO_Clasp: CD1.4 (X_5), U4.3 (Output)
GND: C1.1, C2.1, C3.1, C4.1, C5.2, C6.1, C7.1, C8.1, C9.2, C10.2, C11.1, C12.1, C13.1, C14.1, C15.1, C16.1, C17.1, C18.1, C19.1, C20.2, C21.1, C22.1, C24.2, C25.2, C26.2, C27.1, C28.1, C29.2, C30.2, C31.2, C32.2, C33.1, C34.1, C35.1, C36.2, C37.2, C38.2, C39.2, C44.2, C45.1, C46.1, C47.2, C48.2, C49.2, C50.2, C51.2, CD1.12 (VSS), J3.1, J4.1, J_3.4, R8.2, R9.2, R10.2, R11.2, R12.1, R13.1, R14.1, R15.1, R16.2, R18.2, R19.1, R20.1, R21.1, R22.2, R23.2, R24.1, R25.1, R26.1, R27.1, R36.1, R37.1, R39.1, U1.3 (GND), U1.5 (GND), U1.21 (GND), U2.6 (GND), U2.7 (RESV), U2.11 (RESV), U3.7 (GND), U4.2 (GND), U5.22 (GND_2), U5.53 (GND), U5.63 (GND_3), U6.3 (CURRENT_MODE), U6.10 (GND), U7.6 (INH), U7.7 (VEE), U7.8 (GND), U7.9 (B), U8.6 (INH), U8.7 (VEE), U8.8 (GND), U9.2 (GND), U12.2 (~EN), U12.5 (GND), U13.1 (GND), U_1.3 (GND), U_1.11 (GND), Y1.2 (G), Y1.4 (G), Y2.2 (G), Y2.4 (G)
unnamed: C4.2, SW_1.1
unnamed: C22.2, SW_2.1
unnamed: D1.1 (A), R3.1
unnamed: D2.1 (A), R4.1
unnamed: D3.2 (K), R20.2
unnamed: D4.2 (K), R21.2
unnamed: D5.1 (A), R30.2
unnamed: D5.2 (K), R31.1, U8.3 (Y)
unnamed: D6.1 (A), R33.2
unnamed: C40.2, C41.2, C42.1, C43.1, J5.1, J5.G, U9.4 (0V), U10.3 (C), U10.5 (GND), U11.5 (GND)
unnamed: J5.2, U11.7 (B)
unnamed: J_1.A5 (CC1), R26.2, U6.1 (CC1)
unnamed: J_1.B5 (CC2), R27.2, U6.2 (CC2)
unnamed: C31.1, J_1.SH (SHIELD), R22.1
unnamed: J_2.A5 (CC1), R24.2
unnamed: J_2.B5 (CC2), R25.2
unnamed: C32.1, J_2.SH (SHIELD), R23.1
unnamed: C1.2, U1.20 (AREF)
unnamed: C6.2, U1.7 (XTAL1/TOSC1/PCINT6/PB6), Y1.1
unnamed: C7.2, U1.8 (XTAL2/TOSC2/PCINT7/PB7), Y1.3
unnamed: U2.13 (AP_SCK), U3.3 (A2)
unnamed: U2.14 (AP_SDA), U3.2 (A1)
unnamed: TP9.1, U5.61 (PF0_(ADC0))
unnamed: TP10.1, U5.60 (PF1_(ADC1))
unnamed: TP11.1, U5.59 (PF2_(ADC2))
unnamed: TP12.1, U5.58 (PF3_(ADC3))
unnamed: TP13.1, U5.57 (PF4_(ADC4/TCK))
unnamed: TP14.1, U5.56 (PF5_(ADC5/TMS))
unnamed: TP15.1, U5.55 (PF6_(ADC6/TDO))
unnamed: TP16.1, U5.54 (PF7_(ADC7/TDI))
unnamed: TP3.1, U5.33 (PG0_(~WR))
unnamed: TP4.1, U5.34 (PG1_(~RD))
unnamed: TP5.1, U5.43 (PG2_(ALE))
unnamed: TP6.1, U5.18 (PG3_(TOSC2))
unnamed: TP7.1, U5.19 (PG4_(TOSC1))
unnamed: TP8.1, U5.1 (PG5_(OC0B))
unnamed: C21.2, U5.24 (XTAL1), Y2.3
unnamed: C20.1, U5.23 (XTAL2), Y2.1
unnamed: R29.1, U6.5 (VBUS_DET)
unnamed: U7.13 (X), U8.14 (X1)
unnamed: U7.3 (Y), U8.5 (Y1)
unnamed: U8.12 (X0), U_1.6 (RXD)
unnamed: R32.1, U8.13 (X)
unnamed: R34.2, U10.2 (A)
unnamed: C40.1, C41.1, C42.2, C43.2, R35.2, U9.3 (+VO), U10.7 (EN), U10.8 (VCC), U11.2 (~RE), U11.3 (DE), U11.8 (VCC)
unnamed: R35.1, U10.6 (VO), U11.4 (DI)
unnamed: J5.3, U11.6 (A)
unnamed: R36.2, U12.4 (ILIM)
unnamed: R38.2, U12.3 (VSNS)
unnamed: C35.2, U_1.10 (V3)
VBUS: C29.1, C30.1, C45.2, C46.2, D3.1 (A), D4.1 (A), R29.2, R38.1, R39.2, U12.6 (IN2), U12.8 (IN1)
VCC: C2.2, C3.2, C5.1, C24.1, C25.1, C26.1, C33.2, C34.2, C36.1, C37.1, C38.1, C39.1, C48.1, C49.1, CD1.24 (VDD), FSR_1.2, FSR_2.2, FSR_3.2, FSR_4.2, FSR_5.2, FS_1.2, FS_2.2, FS_3.2, FS_4.2, FS_5.2, FS_6.2, J3.11, J4.6, J_3.1, R1.2, R2.2, R3.2, R4.2, R5.2, R6.2, R7.2, R17.2, R28.1, R30.1, R33.1, U1.4 (VCC), U1.6 (VCC), U1.18 (AVCC), U3.14 (V_{CCB}), U5.21 (VCC_2), U5.52 (VCC), U5.64 (AVCC), U6.12 (VDD), U7.16 (VCC), U8.16 (VCC), U9.1 (VIN), U12.7 (OUT), U13.3 (Vin), U_1.7 (VCC)

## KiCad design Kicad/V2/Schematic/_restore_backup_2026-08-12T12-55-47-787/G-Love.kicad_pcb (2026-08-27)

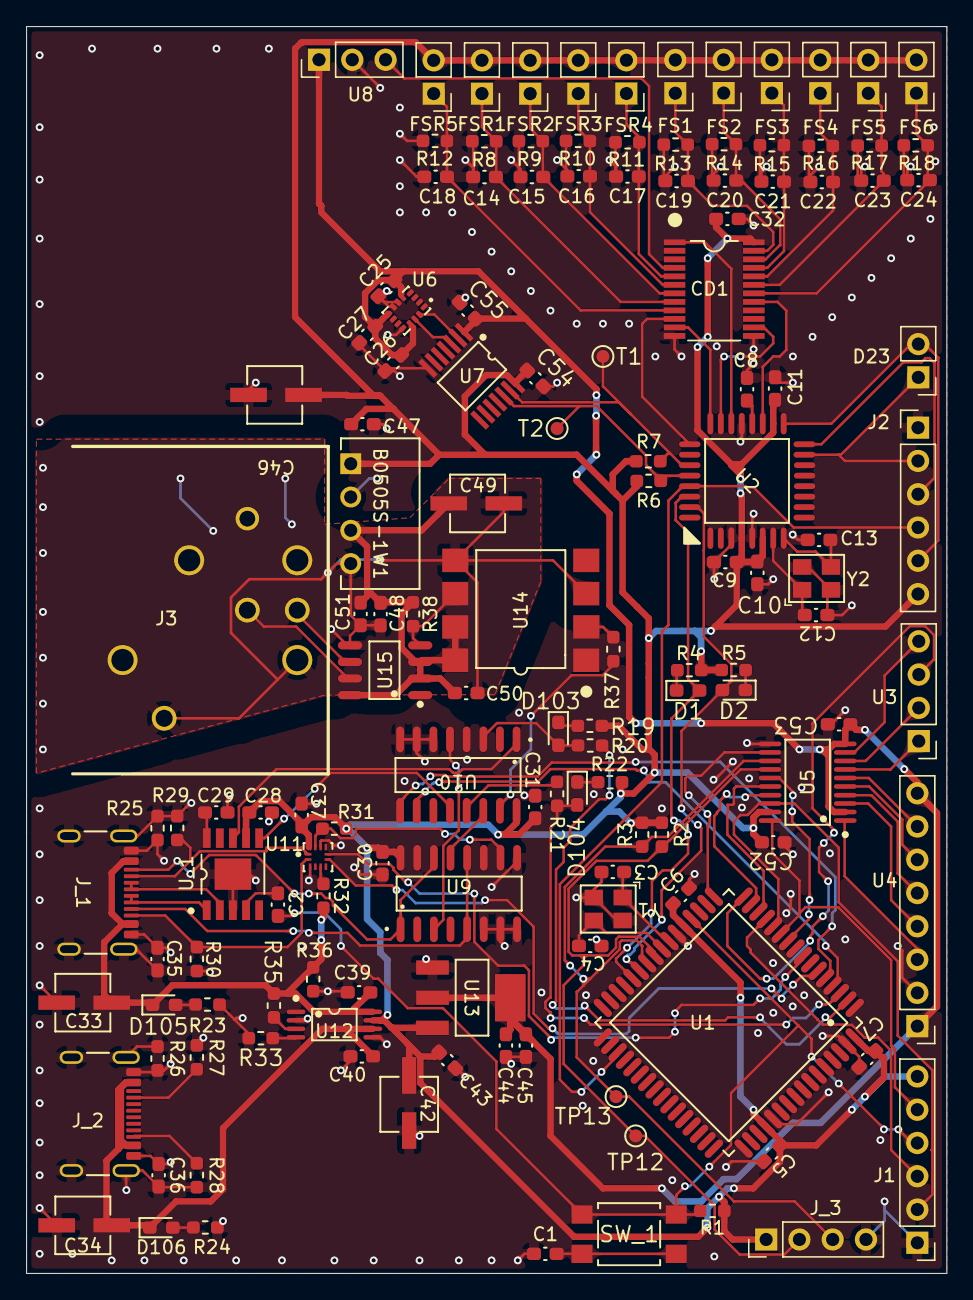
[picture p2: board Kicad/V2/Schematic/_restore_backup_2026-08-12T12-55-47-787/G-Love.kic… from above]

Board: 2 copper layers, 70.3 x 95.2 mm, 139 parts (0 on the bottom side), 96 nets.

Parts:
B0505S-1W1: B0505S
C1, C2, C5, C6, C7, C8, C9, C10, C11, C28, C29, C30, C31, C32, C37, C43, C45, C47, C48, C50, C51, C52, C53, C54, C55: 100nF; Capacitor_0603
C3, C4, C12, C13: 12pF; Capacitor_0603
C14, C15, C16, C17, C18, C19, C20, C21, C22, C23, C24: 47pF; Capacitor_0603
C25, C35: 10nF; Capacitor_0603
C26: 2.2nF; Capacitor_0603
C27: 0.1nF; Capacitor_0603
C33, C34, C42, C46, C49: 4.7uF; Capacitor_Electrolytic
C36: 10n; Capacitor_0603
C39, C40: 1uF; Capacitor_0603
C44: 10uF; Capacitor_0603
CD1: CD4097B
D1, D2, D103, D104: YELLOW; D_0603_1608Metric_Pad1.05x0.95mm_HandSolder
D23: PinHeader_1x02_P2.54mm_Vertical
D105, D106: RED; D_0603_1608Metric_Pad1.05x0.95mm_HandSolder
FS1, FS2, FS3, FS4, FS5, FS6: PinHeader_1x02_P2.54mm_Vertical
FSR1, FSR2, FSR3, FSR4, FSR5: PinHeader_1x02_P2.54mm_Vertical
J1, J2: PinHeader_1x06_P2.54mm_Vertical
J3: XLR5_Ground; XLR5_Connector_Female_CONN-TH_NC5FAH
J_1, J_2: Conn_USB_Receptacle; USB_C_Receptacle_GCT_USB4105-xx-A_16P_TopMnt_Horizontal
J_3: PinHeader_1x04_P2.54mm_Vertical
R1, R8, R9, R10, R11, R12, R13, R14, R15, R16, R17, R18, R31, R36: 10kΩ; Resistor_0603
R2, R3, R6, R7: 2.2kΩ; Resistor_0603
R4, R5, R19, R20, R21, R22, R23, R24: 1k; Resistor_0603
R25, R26: 1M; Resistor_0603
R27, R28, R29, R30: 5.1k; Resistor_0603
R32: 900K; Resistor_0603
R33: 560R; Resistor_0603
R35: 47k; Resistor_0603
R37: 330R; Resistor_0603
R38: 4.7k; Resistor_0603
SW_1: SW_SPST_TL3305A
T1, T2: TestPoint_Pad_D1.0mm
TP12, TP13: TestPoint_Pad_D1.0mm
U1: ATMEGA2561-16AU; ATMega2561
U2: ATMega328P; ATMega328P-AU
U3: CST816D; PinHeader_1x04_P2.54mm_Vertical_CST816D
U4: GC9A01_TFT; PinHeader_1x08_P2.54mm_Vertical
U5: TXS0108EPWR; MTXS0108EPWR
U6: ICM-42688-P_I2C; ICM-42688-P
U7: TXS0104E; TXS0104EPWR
U8: Hall Sensor A3144; PinHeader_1x03_P2.54mm_Vertical
U9, U10: 74HC4052
U11: TUSB321
U12: TPS2113APWR; TPS2113
U13: AMS1117
U14: 6N137
U15: MAX485E; MAX485ED
U_1: CH340K
Y1, Y2: 16MHz; Crystal_16MHz

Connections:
+3.3V: C25.2, C26.1, C27.1, C44.1, C45.1, C53.1, C55.2, U4.1 (VCC), U4.8 (BLK), U5.2 (V_{CCA}), U5.10 (OE), U6.5 (VDDIO), U6.8 (VDD), U6.12 (VDDIO), U7.1 (V_{CCA}), U8.1 (VCC), U13.2 (Vout)
/DTR: C2.2, U_1.4 (~DTR)
/Data/power I/O/2561_UART_RX: R20.2, U1.2 (PE0_(RXD0/PCINT8/PDI))
/Data/power I/O/2561_UART_TX: D104.2 (K), R21.2, U1.3 (PE1_(TXD0/PDO))
/Data/power I/O/Data/DMX/TX_DMX: R37.1, U10.15 (X2)
/Data/power I/O/Data/SBU1: J_1.A8 (SBU1), U9.5 (Y1), U9.12 (X0)
/Data/power I/O/Data/SBU2: J_1.B8 (SBU2), U9.1 (Y0), U9.14 (X1)
/Data/power I/O/Data/UD+: J_1.A7 (D+), J_1.B6 (D+), U_1.1 (UD+)
/Data/power I/O/Data/UD-: J_1.A6 (D-), J_1.B7 (D-), U_1.2 (UD-)
/Data/power I/O/Data/USB_SELECT: R31.2, U9.10 (A), U11.11 (DIR)
/Data/power I/O/Power/BATTERY_USB: C34.1, C40.2, D106.1 (A), J_2.A4 (VBUS2), J_2.A9 (VBUS2), J_2.B4 (VBUS2), J_2.B9 (VBUS2), U12.6 (IN2)
/Data/power I/O/UART_MUX_SEL_A: U1.4 (PE2_(XCK0/AIN0)), U10.10 (A)
/Data/power I/O/UART_MUX_SEL_B: U1.5 (PE3_(OC3A/AIN1)), U10.9 (B)
/Data/power I/O/USB_INT1: U1.6 (PE4_(OC3B/INT4)), U11.7 (OUT1)
/Data/power I/O/USB_INT2: U1.8 (PE6_(T3/INT6)), U11.8 (OUT2)
/FingerTip Modules/FingerTip_I2C_SCL: J_3.2, R2.1, TP12.1, U1.25 ((SCL/INT0)_PD0), U5.14 (B6)
/FingerTip Modules/FingerTip_I2C_SDA: J_3.3, R3.1, TP13.1, U1.26 ((SDA/INT1)_PD1), U5.13 (B7)
/Hand_Captors/ADC_Mux_Select_A: CD1.10 (A), U2.25 (ADC2/PCINT10/PC2)
/Hand_Captors/ADC_Mux_Select_B: CD1.14 (C), U2.23 (ADC0/PCINT8/PC0)
/Hand_Captors/ADC_Mux_Select_C: CD1.11 (B), U2.24 (ADC1/PCINT9/PC1)
/Hand_Captors/ADC_X_Output: CD1.1 (X_OutIn), U2.22 (ADC7)
/Hand_Captors/ADC_Y_Output: CD1.17 (Y_OutIn), U2.19 (ADC6)
/Hand_Captors/FSR_Index/TouchADC: C14.2, CD1.8 (X_1), FSR1.1, R8.2
/Hand_Captors/FSR_Little/TouchADC: C17.2, CD1.5 (X_4), FSR4.1, R11.2
/Hand_Captors/FSR_Middle/TouchADC: C15.2, CD1.7 (X_2), FSR2.1, R9.2
/Hand_Captors/FSR_Ring/TouchADC: C16.2, CD1.6 (X_3), FSR3.1, R10.2
/Hand_Captors/FSR_Thumb/TouchADC: C18.2, CD1.9 (X_0), FSR5.1, R12.2
/Hand_Captors/Flex_Sensor0/FlexADC: C19.2, CD1.23 (Y_0), FS1.1, R13.1
/Hand_Captors/Flex_Sensor1/FlexADC: C20.2, CD1.22 (Y_1), FS2.1, R14.1
/Hand_Captors/Flex_Sensor2/FlexADC: C21.2, CD1.21 (Y_2), FS3.1, R15.1
/Hand_Captors/Flex_Sensor3/FlexADC: C22.2, CD1.20 (Y_3), FS4.1, R16.1
/Hand_Captors/Flex_Sensor4/FlexADC: C23.2, CD1.19 (Y_4), FS5.1, R17.1
/Hand_Captors/Flex_Sensor5/FlexADC: C24.2, CD1.18 (Y_5), FS6.1, R18.1
/Hand_Captors/HallCaptor/HallGPIO_Clasp: CD1.4 (X_5), U8.3 (Output)
/Hand_Captors/I2C_IMU_SDA: R7.1, T1.1, U2.27 (SDA/ADC4/PSCINT12/PC4), U7.13 (B1)
/Hand_Captors/I2C_IMU_SDK: R6.1, T2.1, U2.28 (SCL/ADC5/PCINT13/PC5), U7.12 (B2)
/MCU_328_RESET: J2.4, U1.35 (PC0_(A8)), U2.29 (~RESET/PCINT14/PC6)
/MCU_2561_RESET: C2.1, J1.4, R1.1, SW_1.2, U1.20 (~RESET)
/MISO_BOOT_328P: D23.1 (SDI), J2.2, U2.15 (OC2A/MOSI/PCINT3/PB3)
/MISO_BOOT_2561: J1.2, U1.12 ((MOSI/PCINT2)_PB2), U5.18 (B2)
/MOSI_BOOT_328P: J2.3, U2.16 (MISO/PCINT4/PB4)
/MOSI_BOOT_2561: J1.3, U1.13 ((MISO/PCINT3)_PB3)
/SCK_BOOT_328P: D23.2 (CKI), J2.5, U2.17 (SCK/PCINT5/PB5)
/SCK_BOOT_2561: J1.5, U1.11 ((SCK/PCINT1)_PB1), U5.20 (B1)
/Touchscreen/Screen_D/C: U1.14 ((OC2A/_PCINT4)_PB4), U5.16 (B4)
/Touchscreen/Screen_RESET: U1.15 ((OC1A/PCINT5)_PB5), U5.17 (B3)
/Touchscreen/Screen_SPI_SS: U1.10 ((~SS/PCINT0)_PB0), U5.15 (B5)
/Touchscreen/Touch_I2C_INT: U1.16 ((OC1B/PCINT6)_PB6), U3.5 (TP_INT)
/Touchscreen/Touch_RESET: U1.17 ((OC0A/OC1C/PCINT7)_PB7), U5.12 (B8)
GND: B0505S-1W1.2 (GND), C1.1, C3.2, C4.1, C5.1, C6.1, C7.1, C8.1, C9.1, C10.2, C11.2, C12.1, C13.1, C14.1, C15.1, C16.1, C17.1, C18.1, C19.1, C20.1, C21.1, C22.1, C23.1, C24.1, C25.1, C26.2, C27.2, C28.1, C29.1, C30.2, C31.2, C32.1, C33.2, C34.2, C35.1, C35.2, C36.1, C36.2, C37.1, C39.1, C40.1, C42.2, C43.2, C44.2, C45.2, C46.2, C47.2, C52.1, C53.2, C54.2, C55.1, CD1.12 (VSS), CD1.13 (INHIBIT), J1.1, J2.1, J_1.A1 (GND), J_1.A12 (GND), J_1.B1 (GND), J_1.B12 (GND), J_1.SH (SHIELD), J_2.A1 (GND), J_2.A12 (GND), J_2.B1 (GND), J_2.B12 (GND), J_2.SH (SHIELD), J_3.4, R8.1, R9.1, R10.1, R11.1, R12.1, R13.2, R14.2, R15.2, R16.2, R17.2, R18.2, R23.1, R24.1, R25.1, R25.2, R26.1, R26.2, R27.1, R28.1, R29.2, R30.1, R33.1, R36.1, U1.22 (GND_2), U1.53 (GND), U1.63 (GND_3), U2.3 (GND), U2.5 (GND), U2.21 (GND), U4.2 (GND), U5.11 (GND), U6.6 (GND), U6.7 (RESV), U6.11 (RESV), U7.7 (GND), U8.2 (GND), U9.6 (INH), U9.7 (VEE), U9.8 (GND), U9.9 (B), U10.6 (INH), U10.7 (VEE), U10.8 (GND), U11.3 (CURRENT_MODE), U11.10 (GND), U12.2 (~EN), U12.5 (GND), U13.1 (GND), U_1.3 (GND), U_1.11 (GND), Y1.2 (G), Y1.4 (G), Y2.2 (G), Y2.4 (G)
unnamed: B0505S-1W1.4 (0V), C48.2, C49.2, C50.1, C51.1, J3.1, J3.G, U14.3 (C), U14.5 (GND), U15.5 (GND)
unnamed: B0505S-1W1.3 (+VO), C48.1, C49.1, C50.2, C51.2, R38.2, U14.7 (EN), U14.8 (VCC), U15.2 (~RE), U15.3 (DE), U15.8 (VCC)
unnamed: C1.2, SW_1.1
unnamed: D1.1 (A), R4.2
unnamed: D1.2 (K), U1.28 ((TXD1/INT3)_PD3), U2.30 (RDX/PCINT16/PD0)
unnamed: D2.1 (A), R5.2
unnamed: D2.2 (K), U1.27 ((RXD1/INT2)_PD2), U2.31 (TXD/PCINT17/PD1)
unnamed: D103.1 (A), R19.2
unnamed: D103.2 (K), R20.1, U10.3 (Y)
unnamed: D104.1 (A), R22.2
unnamed: D105.2 (K), R23.2
unnamed: D106.2 (K), R24.2
unnamed: J3.2, U15.7 (B)
unnamed: J_1.A5 (CC1), R29.1, U11.1 (CC1)
unnamed: J_1.B5 (CC2), R30.2, U11.2 (CC2)
unnamed: J_2.A5 (CC1), R27.2
unnamed: J_2.B5 (CC2), R28.2
unnamed: C4.2, U1.24 (XTAL1), Y1.3
unnamed: C3.1, U1.23 (XTAL2), Y1.1
unnamed: C8.2, U2.20 (AREF)
unnamed: C12.2, U2.7 (XTAL1/TOSC1/PCINT6/PB6), Y2.1
unnamed: C13.2, U2.8 (XTAL2/TOSC2/PCINT7/PB7), Y2.3
unnamed: U3.3 (TP_SCL), U5.7 (A6)
unnamed: U3.4 (TP_SDA), U5.8 (A7)
unnamed: U3.16 (TP_~RESET), U5.9 (A8)
unnamed: U4.7 (CS), U5.6 (A5)
unnamed: U4.6 (DC), U5.5 (A4)
unnamed: U4.3 (SCL/SCK), U5.1 (A1)
unnamed: U4.4 (SDA/MOSI), U5.3 (A2)
unnamed: U4.5 (~RESET), U5.4 (A3)
unnamed: U6.13 (AP_SCK), U7.3 (A2)
unnamed: U6.14 (AP_SDA), U7.2 (A1)
unnamed: U10.12 (X0), U_1.6 (RXD)
unnamed: U9.13 (X), U10.14 (X1)
unnamed: R21.1, U10.13 (X)
unnamed: U10.1 (Y0), U_1.8 (TXD)
unnamed: U9.3 (Y), U10.5 (Y1)
unnamed: R32.1, U11.5 (VBUS_DET)
unnamed: R33.2, U12.4 (ILIM)
unnamed: R35.2, U12.3 (VSNS)
unnamed: R37.2, U14.2 (A)
unnamed: R38.1, U14.6 (VO), U15.4 (DI)
unnamed: J3.3, U15.6 (A)
unnamed: C29.2, U_1.10 (V3)
VBUS1: C33.1, C39.2, D105.1 (A), J_1.A4 (VBUS1), J_1.A9 (VBUS1), J_1.B4 (VBUS1), J_1.B9 (VBUS1), R32.2, R35.1, R36.2, U12.8 (IN1)
VCC: B0505S-1W1.1 (VIN), C5.2, C6.2, C7.2, C9.2, C10.1, C11.1, C28.2, C30.1, C31.1, C32.2, C37.2, C42.1, C43.1, C46.1, C47.1, C52.2, C54.1, CD1.24 (VDD), FS1.2, FS2.2, FS3.2, FS4.2, FS5.2, FS6.2, FSR1.2, FSR2.2, FSR3.2, FSR4.2, FSR5.2, J1.6, J2.6, J_3.1, R1.2, R2.2, R3.2, R4.1, R5.1, R6.2, R7.2, R19.1, R22.1, R31.1, U1.21 (VCC_2), U1.52 (VCC), U1.64 (AVCC), U2.4 (VCC), U2.6 (VCC), U2.18 (AVCC), U5.19 (V_{CCB}), U7.14 (V_{CCB}), U9.16 (VCC), U10.16 (VCC), U11.12 (VDD), U12.7 (OUT), U13.3 (Vin), U_1.7 (VCC)

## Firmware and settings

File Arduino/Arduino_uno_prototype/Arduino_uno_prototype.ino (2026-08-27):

#include <Adafruit_ICM20948.h>
#include <Adafruit_ICM20X.h>
#include <Adafruit_Sensor.h>
#include <FastLED.h>
#include <Wire.h>

// Définition des broche pour les LED
#define NUM_LEDS 20
#define DATA_PIN 8  // Fil DI connecté sur la broche 8
#define CLOCK_PIN 9 // Fil CI connecté sur la broche 9
CRGB leds[NUM_LEDS];

// Définition des broches de sélection
const int S0 = 2;
const int S1 = 3;
const int S2 = 4;
const int S3 = 5;
const int EN = 7;
// Broche de lecture commune
const int SIG = 14;

const float seuilInclinaisonX = 3.0;
const float seuilInclinaisonY = 3.0;
const float seuilInclinaisonZ = 3.0;

Adafruit_ICM20948 icm;

// Fonction pour configurer les broches de sélection selon le canal désiré (0 à
// 15)
void selectChannel(int channel) {
  digitalWrite(S0, (channel & 1));
  digitalWrite(S1, (channel & 2) >> 1);
  digitalWrite(S2, (channel & 4) >> 2);
  digitalWrite(S3, (channel & 8) >> 3);
}

int readChannel(int channel) {
  selectChannel(channel);
  delayMicroseconds(50);
  int etat = analogRead(SIG);
  delayMicroseconds(50);
  etat = analogRead(SIG);

  // Affichage résultats
  Serial.print("Canal C" + String(channel) + "  -> ");
  Serial.println(etat);
  return etat;
}

void readAllChannels(int max) {
  for (int i = 0; i < max && i < 16; i++) {
    readChannel(i);
  }
}

void setup(void) {
  Serial.begin(115200);
  while (!Serial) {
    delay(10);
  }

  Serial.println("Init ruban LED APA102");
  FastLED.addLeds<APA102, DATA_PIN, CLOCK_PIN, BGR>(leds, NUM_LEDS);
  // FastLED.setBrightness(50);

  fill_solid(leds, NUM_LEDS, CHSV(CRGB::White, 128, 8));
  FastLED.show();
  delay(500);
  fill_solid(leds, NUM_LEDS, CHSV(CRGB::Black, 128, 8));
  FastLED.show();

  Wire.setClock(100000);

  pinMode(S0, OUTPUT);
  pinMode(S1, OUTPUT);
  pinMode(S2, OUTPUT);
  pinMode(S3, OUTPUT);
  pinMode(EN, OUTPUT);

  pinMode(SIG, INPUT);
  digitalWrite(EN, 1);

  Serial.println("Init ICM-20948");
  // Initialisation I2C (adresse 0x68 pour Pimoroni)
  if (!icm.begin_I2C(0x68)) {
    Serial.println("Erreur: no sensor found");
    while (1) {
      delay(10);
    }
  }
  Serial.println("ICM-20948 ready");
}

String dataX;
String dataY;
String dataZ;

void loop() {
  sensors_event_t accel;
  sensors_event_t gyro;
  sensors_event_t mag;
  sensors_event_t temp;

  // Lecture des capteurs de l'ICM20948
  icm.getEvent(&accel, &gyro, &temp, &mag);

  float valeurX = accel.acceleration.x;
  float valeurY = accel.acceleration.y;
  float valeurZ = accel.acceleration.z;

  // Limitation de la valeur X entre -9.81 et +9.81 m/s^2
  if (valeurX < -9.81)
    valeurX = -9.81;
  if (valeurX > 9.81)
    valeurX = 9.81;

  // Limitation de la valeur Y entre -9.81 et +9.81 m/s^2
  if (valeurY < -9.81)
    valeurY = -9.81;
  if (valeurY > 9.81)
    valeurY = 9.81;

  // Limitation de la valeur Z entre -9.81 et +9.81 m/s^2
  if (valeurZ < -9.81)
    valeurZ = -9.81;
  if (valeurZ > 9.81)
    valeurZ = 9.81;

  dataX = "X: " + String(valeurX) + "m/s^2";
  dataY = " Y: " + String(valeurY) + " m/s^2; ";
  dataZ = " Z: " + String(valeurZ) + " m/s^2\n";
  Serial.print(dataX + dataY + dataZ);

  // Formatage des valeurs pour les LED
  long xCentiemes = valeurX * 100;
  uint8_t hueX = map(xCentiemes, -981, 981, 160, 0);

  long yCentiemes = valeurY * 100;
  uint8_t hueY = map(yCentiemes, -981, 981, 160, 0);

  long zCentiemes = valeurZ * 100;
  uint8_t hueZ = map(zCentiemes, -981, 981, 160, 0);

  // logique d'allumage des LED
  // CHSV(Teinte, Saturation, Valeur/Luminosite)
  fill_solid(leds, NUM_LEDS, CHSV(hueX, 128, 8));
  FastLED.show();

  readAllChannels(9);
  delay(200);
}

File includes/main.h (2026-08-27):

#ifndef MAIN_H
#define MAIN_H

#include <avr/io.h>
#include <util/delay.h>
#include <stdint.h>

#if defined(__AVR_ATmega2560__)
    #define SPI_DDR   DDRB
    #define SPI_MOSI  DDB2
    #define SPI_SCK   DDB1
    #define SPI_SS    DDB0
#elif defined(__AVR_ATmega328P__) || defined(__AVR_ATmega328__)
    #define SPI_DDR   DDRB
    #define SPI_MOSI  DDB3
    #define SPI_SCK   DDB5
    #define SPI_SS    DDB2
#endif

typedef struct s_rgb_color
{
    uint8_t red;
    uint8_t green;
    uint8_t blue;
} t_rgb_color;

//adc.c
void		adc_init();
uint8_t		ft_adc_read();
uint16_t 	ft_adc_read_10bit();

// i2c.c
void 		i2c_init(void);
void 		i2c_status(void);
void 		i2c_start(void);
void 		i2c_stop(void);
void 		i2c_write(unsigned char data);
uint8_t 	i2c_read_ack(void);
uint8_t 	i2c_read_nack(void);
void 		i2c_read(void);


//spi.c
void        spi_init();
void        spi_send_data(char data);
void        spi_send_color(t_rgb_color *colors,
                uint16_t number, uint16_t brightness);

// uart.c
void 		uart0_init(unsigned long baudrate);
void 		uart0_tx(char c);
char 		uart0_rx(void);
void 		uart0_printstr(const char *str);
void 		uart0_print_10bit(uint32_t c);

void 		uart1_init(unsigned long baudrate);
void 		uart1_tx(char c);
char 		uart1_rx(void);
void 		uart1_printstr(const char *str);
void 		uart1_print_10bit(uint32_t c);
uint8_t 	uart1_available(void);

uint8_t		ft_hex(uint8_t val);
void 		ft_uart_print_hex(uint8_t c);

#endif

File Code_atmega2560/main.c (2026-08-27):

#include "../includes/config_atm2560.h"
#include "../includes/main.h"

void setup() {
  // uart_init
  uart0_init(BAUDRATE);
  uart1_init(BAUDRATE);

  // pin 7 en input
  DDRD &= ~(1 << DDD7);
  // pullup
  PORTD |= (1 << PORTD7);

  // i2c init
  i2c_init();
}

int main(void) {

  setup();
  char buf[100];
  int i = 0;

  while (1) {
    // uart0_printstr("test\n");
    if (PIND & (1 << PIND7)) {

      i2c_start();
      i2c_write(I2C_ADDR_CST816D << 1 | 0);
      i2c_write(0x01);
      // i2c_read_ack();

      i2c_start();
      i2c_write((I2C_ADDR_CST816D << 1) | 1);

      uint8_t action = i2c_read_ack();
      uint8_t points = i2c_read_ack();
      uint8_t x_high = i2c_read_ack();
      uint8_t x_low = i2c_read_ack();
      uint8_t y_high = i2c_read_ack();
      uint8_t y_low = i2c_read_nack();

      i2c_stop();

      int x = ((x_high & 0x0F) << 8) | x_low;
      int y = ((y_high & 0x0F) << 8) | y_low;

      if (points > 0) {
        uart0_printstr("action: ");
        uart0_print_10bit(action);
        if (action == 1)
          uart0_printstr("swipe up\n");
        else if (action == 2)
          uart0_printstr("swipe down\n");
        else if (action == 3)
          uart0_printstr("swipe right\n");
        else if (action == 4)
          uart0_printstr("swipe left\n");
        else if (action == 0)
          uart0_printstr("tap\n");
        else
          uart0_printstr("autre action\n");
        uart0_printstr("Toucher detecte ! X: ");
        uart0_print_10bit(x);
        uart0_printstr(" | Y: ");
        uart0_print_10bit(y);
        uart0_printstr("\n");
      }
    }
    
    if (uart1_available() > 0)
    {
      char c = uart1_rx();
      if (c == '\n')
      {
        buf[i] = '\0';
        uart0_printstr(buf);
        uart0_printstr("\n");
        i = 0;
      }
      else
      {
        buf[i] = c;
        i++;
      }
    }
  }
  return 0;
}

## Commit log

2026-06-02 Kicad Default Project
    [G-Love.kicad_pcb, G-Love.kicad_sch]
2026-06-02 IMC symbol
    [G-Love.kicad_sch]
2026-06-13 More Symbols and some footprints
    [G-Love.kicad_sch]
2026-06-23 add symbols and notes
    [G-Love.kicad_sch]
2026-06-23 FS and FSR as hierarchical sheets
    [FSR.kicad_sch, FlexSensor.kicad_sch, G-Love.kicad_sch]
2026-06-23 add 328P multiplexer and crystal
    [FSR.kicad_sch, FlexSensor.kicad_sch, G-Love.kicad_sch]
2026-06-24 add prototype visuals
    [Bracer.kicad_sch, FlexSensor.kicad_sch, G-Love.kicad_sch]
2026-06-26 add imu level shifter
    [Bracer.kicad_sch, FSR.kicad_sch, FlexSensor.kicad_sch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]
2026-06-27 add rgb led symbol
    [G-Love.kicad_sch]
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2026-07-11 Started working on libs and defines
    [G-Love.kicad_pcb, G-Love.kicad_sch]
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2026-07-17 Utils to scan the I2C bus for devices, added touchscreen coordinates retrievial function, IMU sampling to minimize noise before returning the values
    [imu.c, imu.h, main.c]
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2026-07-20 add USB conn (ongoing)
    [G-Love.kicad_sch, switch.kicad_sch]
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2026-07-21 group by theme in hierarchical subsheets
    [FSR.kicad_sch, FlexSensor.kicad_sch, G-Love.kicad_sch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]
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2026-07-25 Avancement du schema, ajout d'un LDO pour convertir le 5v et des broches pour le bootloader
    [FSR.kicad_sch, FlexSensor.kicad_sch, G-Love.kicad_sch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]
2026-07-26 Avancement de l'alimentation via USB et batterie externe, reste switch pour uart et condos a faire
    [G-Love.kicad_sch, outputs.kicad_sch, touchscreen.kicad_sch]
2026-07-27 transfert pour pc kevin
    [outputs.kicad_sch]
2026-07-27 multiplexer courant et uart USB C
    [captors.kicad_sch, outputs.kicad_sch]
2026-07-27 DMX fini et isole electriquement, alim finie, reste switch UART automatique
    [dmx.kicad_sch, outputs.kicad_sch]
2026-07-27 Je crois que j'ai fini, je fais l'erc demain en revoyant la logique des switch, notamment les selections avec transistors
    [dmx.kicad_sch, outputs.kicad_sch, power.kicad_sch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]
2026-07-27 To Do : Finir les condo pour chaque broche d'alimentation au moins avec ERC
    [G-Love.kicad_sch, power.kicad_sch, touchscreen.kicad_sch]
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2026-08-04 finished all footprints + redid some symbols, ready for PCB
    [FSR.kicad_sch, FlexSensor.kicad_sch, G-Love.kicad_sch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]
2026-08-04 regle JLCPCB appliquees, pret pour design pousse
    [G-Love.kicad_pcb, G-Love.kicad_sch, outputs.kicad_sch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]
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2026-08-05 update: footprint link to component
    [FSR.kicad_sch, FlexSensor.kicad_sch, G-Love.kicad_sch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]
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2026-08-07 Premier jet PCB, A optimiser
    [FSR.kicad_sch, FlexSensor.kicad_sch, G-Love.kicad_pcb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]
2026-08-09 reste routage mais peu
    [FSR.kicad_sch, FlexSensor.kicad_sch, G-Love.kicad_pcb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]
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2026-08-17 rangement avant merge design
    [G-Love.kicad_pcb, G-Love.kicad_sch]
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2026-08-24 update: icm footprint add pad error
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2026-08-27 on vire tout pour merge la V1
    [G-Love.kicad_pcb, G-Love.kicad_sch]
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2026-09-03 remove level shifter from tft
    [G-Love.kicad_sch, touchscreen.kicad_sch]
2026-09-03 ERC almost done, footprint to assign
    [ATMega2561.kicad_sch, ATmega328P_sch.kicad_sch, FSR.kicad_sch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]
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2026-09-04 add gnd to 2560 quatrz
    [ATMega2561.kicad_sch]
2026-09-07 correction 328p et ajout d'un capa
    [ATMega2561.kicad_sch, ATmega328P_sch.kicad_sch, FSR.kicad_sch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]
2026-09-08 correction schema elec + ajout connecteur FPC
    [ATMega2561.kicad_sch, ATmega328P_sch.kicad_sch, FSR.kicad_sch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]
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2026-09-09 added draft of IMU section in PCB
    [G-Love.kicad_pcb, IMU.kicad_sch]
2026-09-09 Split power and data
    [ATMega2561.kicad_sch, ATmega328P_sch.kicad_sch, G-Love.kicad_sch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]
2026-09-09 finition schematic de reference
    [ATMega2561.kicad_sch, ATmega328P_sch.kicad_sch, Bracer.kicad_sch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]
2026-09-09 hand FPC pass erc no warning no error
    [FSR.kicad_sch, FingerLed.kicad_sch, FlexSensor.kicad_sch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]
2026-09-09 add custom symbol for FPC connector
    [FSR.kicad_sch, FingerLed.kicad_sch, FlexSensor.kicad_sch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]
2026-09-09 fix flex sensor mixed up with force sensor
    [FSR.kicad_sch, FlexSensor.kicad_sch, IMU.kicad_sch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]
2026-09-10 ajout perle ferrite et fusible polymer
    [ATmega328P_sch.kicad_sch, power.kicad_sch]
2026-09-11 Alimentation finalisée & blindage connecteur FPC
    [G-Love.kicad_sch, captors.kicad_sch, power.kicad_sch]
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2026-09-11 fix: pullup res between IMU and level shifter 3.3V
    [IMU.kicad_sch]
2026-09-11 New footprints : Ferrite bead, poly fuse, TVS diode. To do: FPC connector footprint
    [ATMega2561.kicad_sch, ATmega328P_sch.kicad_sch, G-Love.kicad_sch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]
2026-09-11 add edgecut for testing
    [FingerLed.kicad_sch, HandFPC.kicad_pcb]
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2026-09-13 add upper gnd pour
    [HandFPC.kicad_pcb]
2026-09-13 j'aurai du commit avant, j'ai tunnel
    [ATMega2561.kicad_sch, ATmega328P_sch.kicad_sch, Bracer.kicad_sch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]
2026-09-13 update connector to wrist board
    [ATMega2561.kicad_sch, PowerArm.kicad_sch, power.kicad_sch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]
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2026-09-14 route ATmega capa and quarz
    [PowerArm.kicad_pcb]
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2026-09-14 DRC bon, reste serigraphie
    [ATmega328P_sch.kicad_sch, G-Love.kicad_pcb]
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2026-09-15 minor fixes on powerboard
    [HandFPC.kicad_pcb, PowerArm.kicad_pcb]
2026-09-15 touchup on stitching and usb connector footprint
    [PowerArm.kicad_pcb]
2026-09-15 add testpoints and stiffener pads
    [FSR.kicad_sch, FingerLed.kicad_sch, FlexSensor.kicad_sch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]
2026-09-15 add Gerber and BOM
    [HandFPC-B_Cu.gbr, HandFPC-B_Mask.gbr, HandFPC-B_Paste.gbr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]
2026-09-16 minor fixes, add JST connector of better format
    [FingerLed.kicad_sch, HandFPC.kicad_pcb, PowerArm.kicad_pcb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]
2026-09-21 missing FPC addition
    [HandFPC-B_Cu.gbl, HandFPC-B_Mask.gbs, HandFPC-B_Paste.gbp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]
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2026-09-22 update fpc with sewing holes
    [HandFPC-B_Cu.gbl, HandFPC-B_Mask.gbs, HandFPC-B_Paste.gbp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]
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2026-09-24 Led react to uart interrupt
    [ATMega2561.kicad_sch, ATmega328P_sch.kicad_sch, Bracer.kicad_sch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]
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2026-09-25 refactor: pack sensor data structures and fix
    [main.h]
2026-09-25 fix: uart function change
2026-09-27 fix stiffener side indication
    [HandFPC-B_Cu.gbl, HandFPC-B_Mask.gbs, HandFPC-B_Paste.gbp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]
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2026-09-29 fix(i2c): add i2c timeout to stop hanging
    [main.h]
2026-09-30 v5 Gerber with extended format
    [HandFPC-B_Adhesive.gbr, HandFPC-B_Cu.gbr, HandFPC-B_Mask.gbr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]
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2026-10-06 correct silkscreen on FPC
    [HandFPC.kicad_pcb]
2026-10-06 add last drc check on FPC
    [HandFPC.kicad_pcb]
2026-10-06 added disgusting Aisler hand PCB
    [ATMega2561.kicad_sch, ATmega328P_sch.kicad_sch, Bracer.kicad_sch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]
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2026-10-08 prototyping on pure Gc9a01 for now
    [G-Love.kicad_pcb]
2026-10-12 display on broken screen with new JST cables, once again problem was between chips and screen
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2026-10-18 fix: remove interrupt on SPI on ATmega 2561
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2026-10-19 fix mixed refresh due to heavy timer interrupt
2026-10-19 add flex sensor visual with gradient
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2026-10-19 fix low vis yellow on imu screen
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2026-10-19 add Flex sensor data into flexscreen
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2026-10-19 fix: timer register mix up
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2026-10-19 feat(imu): add IMU reset command support
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
